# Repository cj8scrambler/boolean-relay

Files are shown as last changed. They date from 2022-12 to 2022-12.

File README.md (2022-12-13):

# Boolean Relay

Boolean relay is a solid state relay with mutliple inputs.  It's designed for use in a 12V automotive system.  The 12V input is relayed to the output depending on the X, Y and Z inputs.  The logic controlling the output is: (X AND Y) OR ((NOT X) AND Z).  However, it can be used for more common inputs (see below).

## Design 

### Block Diagram
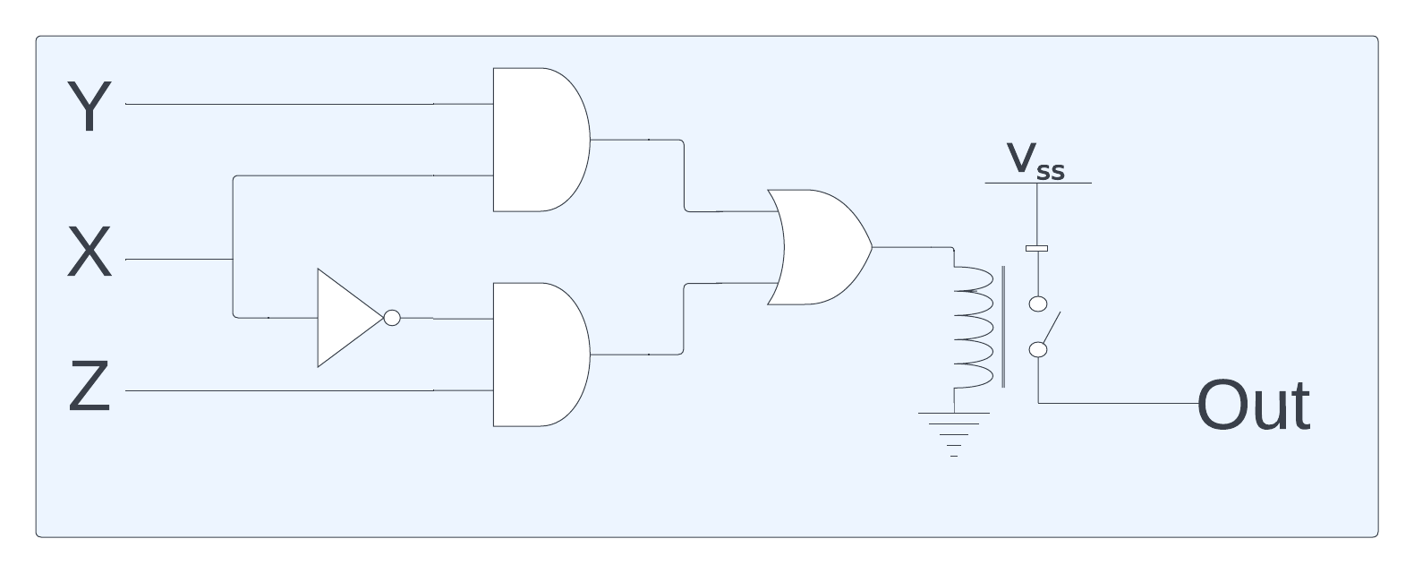
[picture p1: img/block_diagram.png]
block diagram


### Design files
- [schematic PDF](hw/schematic_v6.0.pdf) 
- [layout PDF](hw/layout_v6.0.pdf).
- [schematic KiCad](hw/bool2.kicad_sch) 
- [layout KiCad](hw/bool2.kicad_pcb)

## Configurations

### Without diodes placed
This is the normal configuration.  In this setup, the 12V output line will be powered by the 12V input line.  There is no (well, really close to no) load on the X, Y and Z inputs.

### With diodes placed
The only good use for this is if you want a boolean type control, you don't have a separate 12V input power available and the inputs are capable of driving the output.

If the 3 diodes are placed on the board, then the 12V input power is not required.  The power to drive the output will come from some combination of the input signas (X, Y and/or Z).  It's impossible to say which input will provide the power.

## Uses

### AND 2 Inputs (XY)
**Setup**: None

**Inputs**: X and Y

**Output**: On if both X and Y inputs are on

### OR 2 Inputs (X+Z)
**Setup**: Tie Y input to 12V

**Inputs**: X and Z

**Output**: On if either X or Z input is on

### NOT 1 Input (!X)
**Setup**: Tie Z input to 12V

**Inputs**: X

**Output**: On if X is off, Off if X is on

### Buffer 1 Input (X)
**Setup**: Tie Y input to 12V

**Inputs**: X

**Output**: On if X is on, Off if X is off

### XY + !XZ
**Setup**: None

**Inputs**: X, Y & Z

**Output**: If X is on, output follows Y, if X is off, output follows Z

## Assembly

I use KiCad to generate an [SVG](img/bool2-F_Paste.svg) of the paste layer.  I use a GlowForge to cut a 5 mil peice of mylar for use as a solder mask.  I can then wipe solder paste onto the board, hand place the components, then run it through a T962 reflow oven.

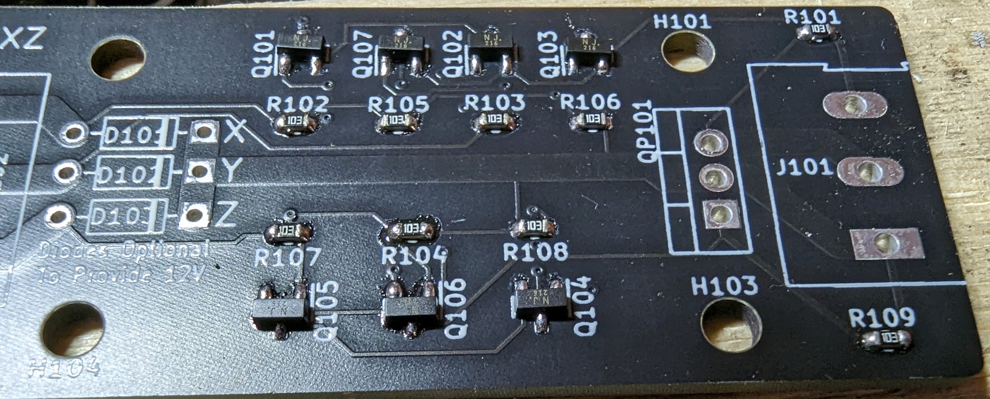
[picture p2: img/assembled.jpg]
assembled board


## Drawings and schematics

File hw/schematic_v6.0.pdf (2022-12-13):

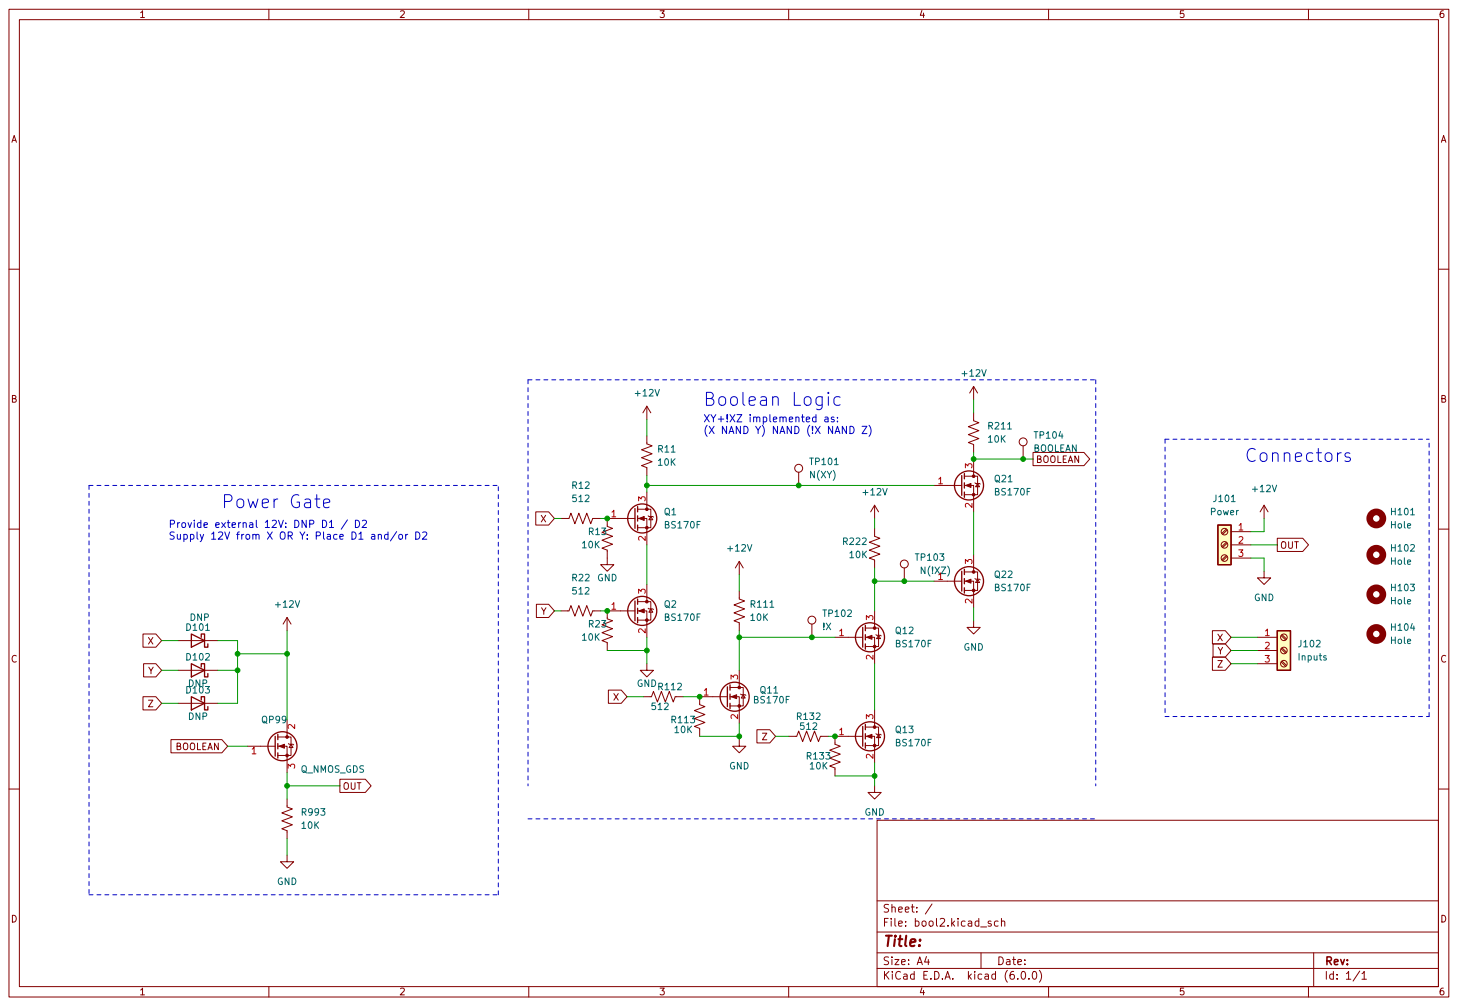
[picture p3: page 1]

XY+!XZ implemented as:

(X NAND Y) NAND (!X NAND Z) Provide external 12V: DNP D1 / D2 Supply 12V from X OR Y: Place D1 and/or D2

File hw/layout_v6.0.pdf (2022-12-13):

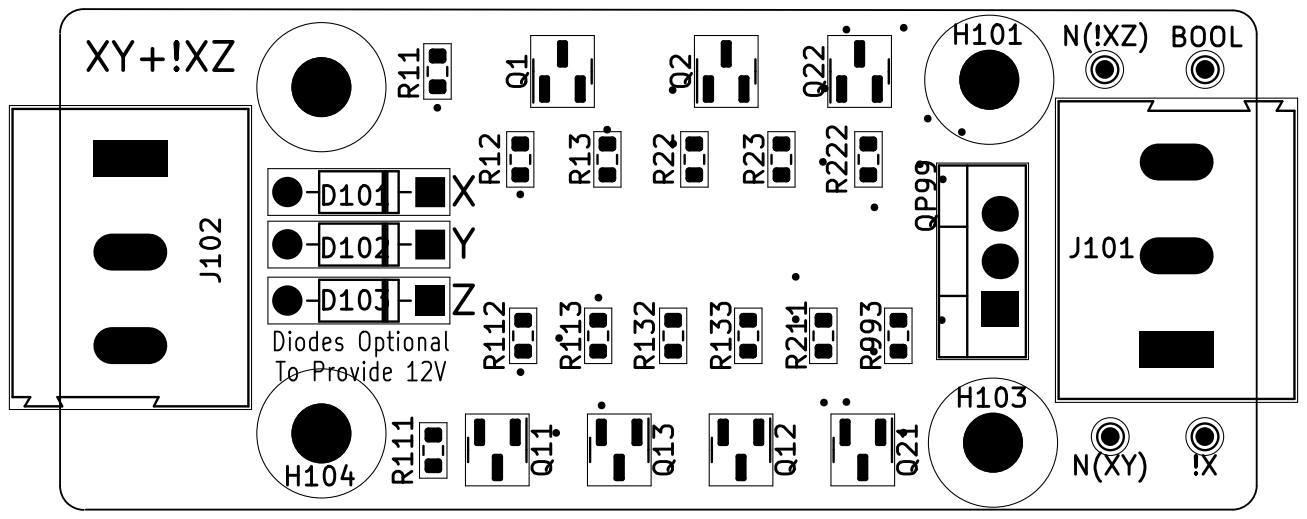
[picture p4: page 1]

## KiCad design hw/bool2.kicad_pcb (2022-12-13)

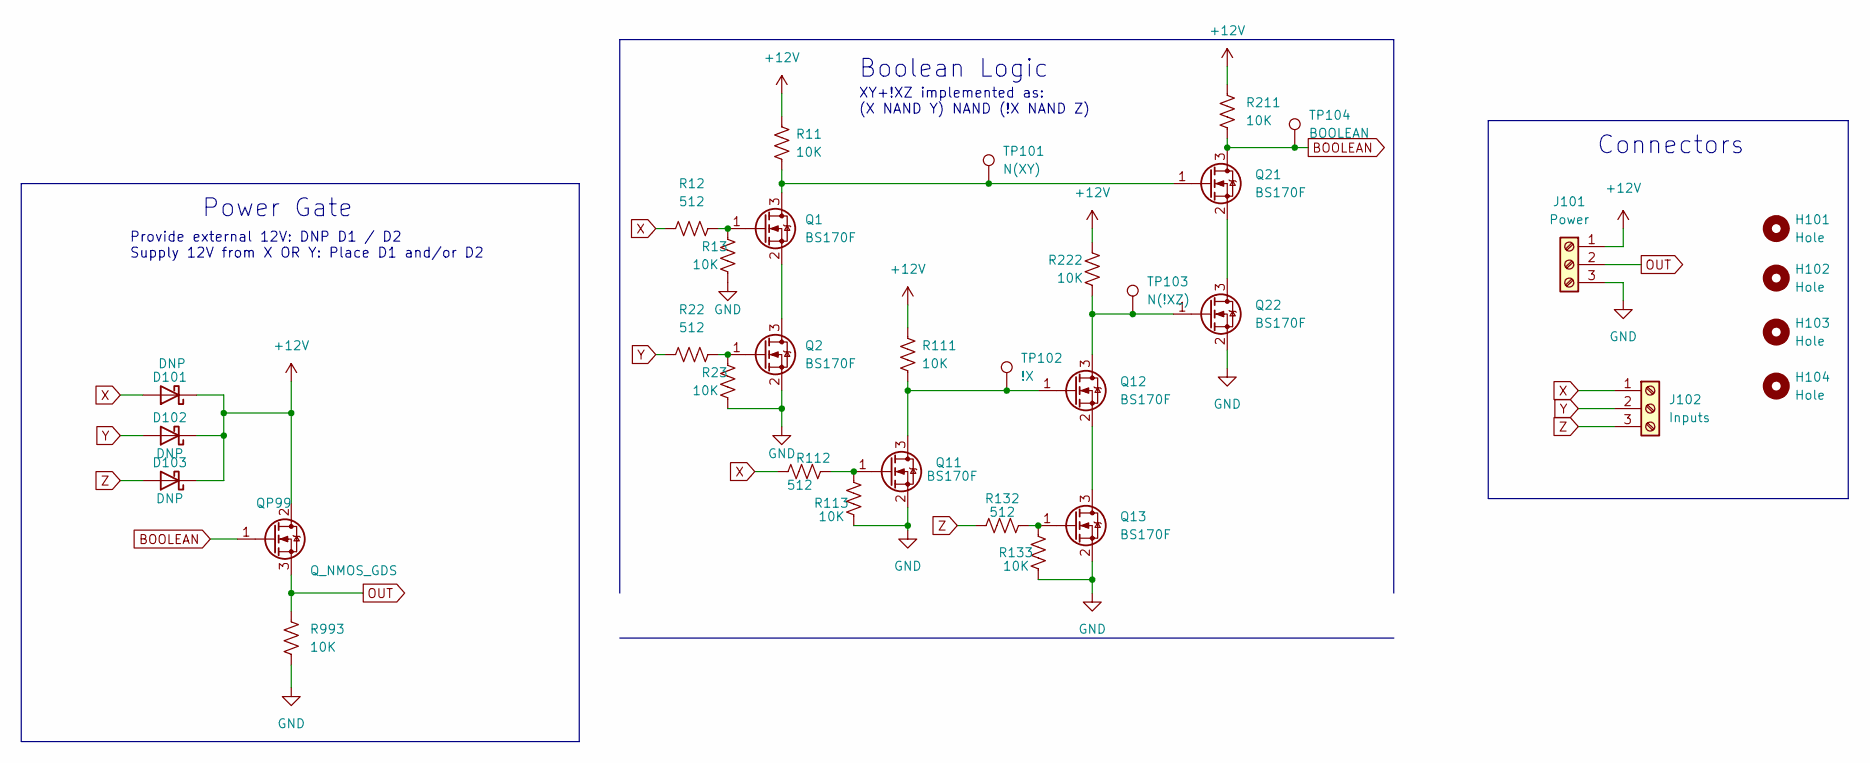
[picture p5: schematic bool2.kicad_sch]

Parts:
D101, D102, D103: DNP; D_DO-35_SOD27_P7.62mm_Horizontal
H101, H102, H103, H104: Hole; MountingHole_3.2mm_M3
J101: Power; TerminalBlock_Altech_AK300-3_P5.00mm
J102: Inputs; TerminalBlock_Altech_AK300-3_P5.00mm
Q1, Q2, Q11, Q12, Q13, Q21, Q22: BS170F; SOT-23
QP99: Q_NMOS_GDS; TO-220-3_Vertical
R11, R13, R23, R111, R113, R133, R211, R222, R993: 10K; R_0603_1608Metric
R12, R22, R112, R132: 512; R_0603_1608Metric
TP101: N(XY); TestPoint_Pad_D1.0mm
TP102: !X; TestPoint_Pad_D1.0mm
TP103: N(!XZ); TestPoint_Pad_D1.0mm
TP104: BOOLEAN; TestPoint_Pad_D1.0mm

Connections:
+12V: D101.1 (K), D102.1 (K), D103.1 (K), J101.1, QP99.2 (D), R11.1, R111.1, R211.1, R222.1
BOOLEAN: Q21.3 (D), QP99.1 (G), R211.2, TP104.1
GND: J101.3, Q2.2 (S), Q11.2 (S), Q13.2 (S), Q22.2 (S), R13.2, R23.2, R113.2, R133.2, R993.2
unnamed: Q1.1 (G), R12.2, R13.1
unnamed: Q1.3 (D), Q21.1 (G), R11.2, TP101.1
unnamed: Q2.1 (G), R22.2, R23.1
unnamed: Q1.2 (S), Q2.3 (D)
unnamed: Q11.1 (G), R112.2, R113.1
unnamed: Q11.3 (D), Q12.1 (G), R111.2, TP102.1
unnamed: Q12.2 (S), Q13.3 (D)
unnamed: Q12.3 (D), Q22.1 (G), R222.2, TP103.1
unnamed: Q13.1 (G), R132.2, R133.1
unnamed: Q21.2 (S), Q22.3 (D)
OUT: J101.2, QP99.3 (S), R993.1
X: D101.2 (A), J102.1, R12.1, R112.1
Y: D102.2 (A), J102.2, R22.1
Z: D103.2 (A), J102.3, R132.1

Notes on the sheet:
Power Gate
XY+!XZ implemented as: (X NAND Y) NAND (!X NAND Z)
Connectors
Boolean Logic
Provide external 12V: DNP D1 / D2 Supply 12V from X OR Y: Place D1 and/or D2

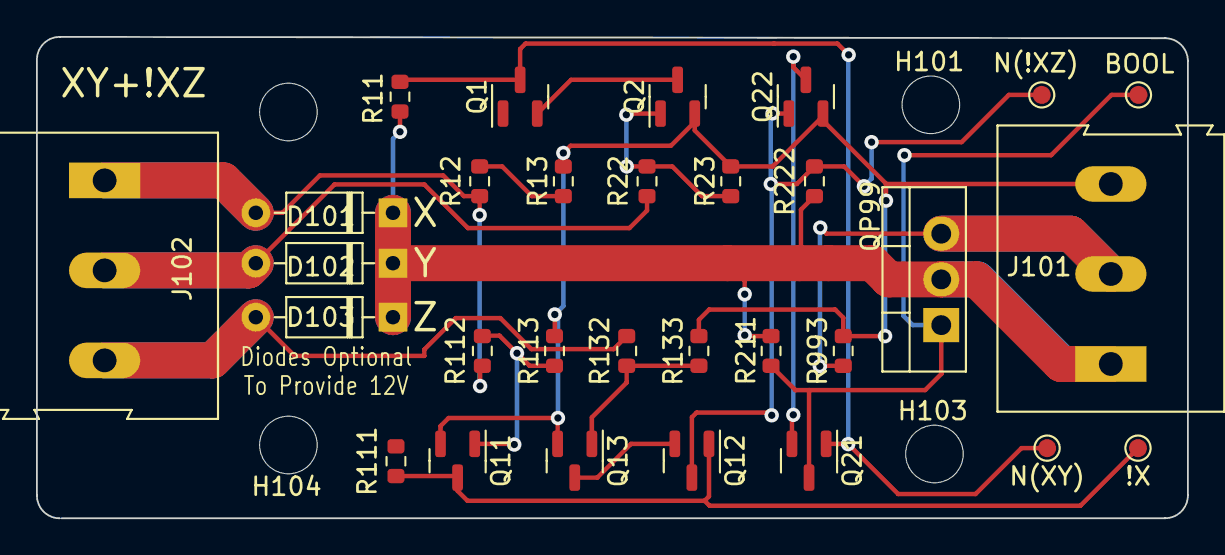
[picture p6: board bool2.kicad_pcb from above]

Board: 2 copper layers, 63.9 x 26.7 mm, 34 parts (0 on the bottom side), 17 nets.
